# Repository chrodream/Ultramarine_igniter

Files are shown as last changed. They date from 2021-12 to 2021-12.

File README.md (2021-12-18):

# Ultramarine Igniter

## Specification

- Ergonomic key style
- OLED unit
- QMK Firmware is Ready
- RGB LED matrix (Optional)
- Li-Po Battery charge circuit included (Optional)

## Parts

- Ultramarine PCBs x 2
- Key switches x 70 (Cherry MX and Kailh low profile v1 are available)
- 1N4148W Diode x 70
- Pro micro x 70 (You can use BLE Pro micro when connect with Bluetooth)
- Reset switches x 2
- TRRS cable x 1 (Only wired connection)

### Optional parts

- SK6812 mini x 70

- OLED working with SSD1306 driver x 2 (128 x 32 pixels)

  #### Battery parts

  - Li-Po batteries x 2 
  - pCh MOSFET (Recommended AO3401)
  - MCP73831
  - DW01A
  - FS8205
  - 4.7uF Capacitor x 3
  - 0.1uF x 1
  - 0.1 Resistor x 1
  - 330

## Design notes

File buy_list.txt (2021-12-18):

main
https://akizukidenshi.com/catalog/g/gP-15370/ SLIDESW
https://akizukidenshi.com/catalog/g/gI-05866/ D
https://akizukidenshi.com/catalog/g/gI-11879/ Pow-LED
https://akizukidenshi.com/catalog/g/gI-15477/ RGB-LED
https://akizukidenshi.com/catalog/g/gC-06070/ TRRS
https://akizukidenshi.com/catalog/g/gP-08074/ TACTSW

battery area
https://www.sengoku.co.jp/mod/sgk_cart/detail.php?code=EEHD-4YZL/ Battery
https://akizukidenshi.com/catalog/g/gI-14654/ Pch MOSFET
https://akizukidenshi.com/catalog/g/gI-13288/ MCP73831 (charge unit)

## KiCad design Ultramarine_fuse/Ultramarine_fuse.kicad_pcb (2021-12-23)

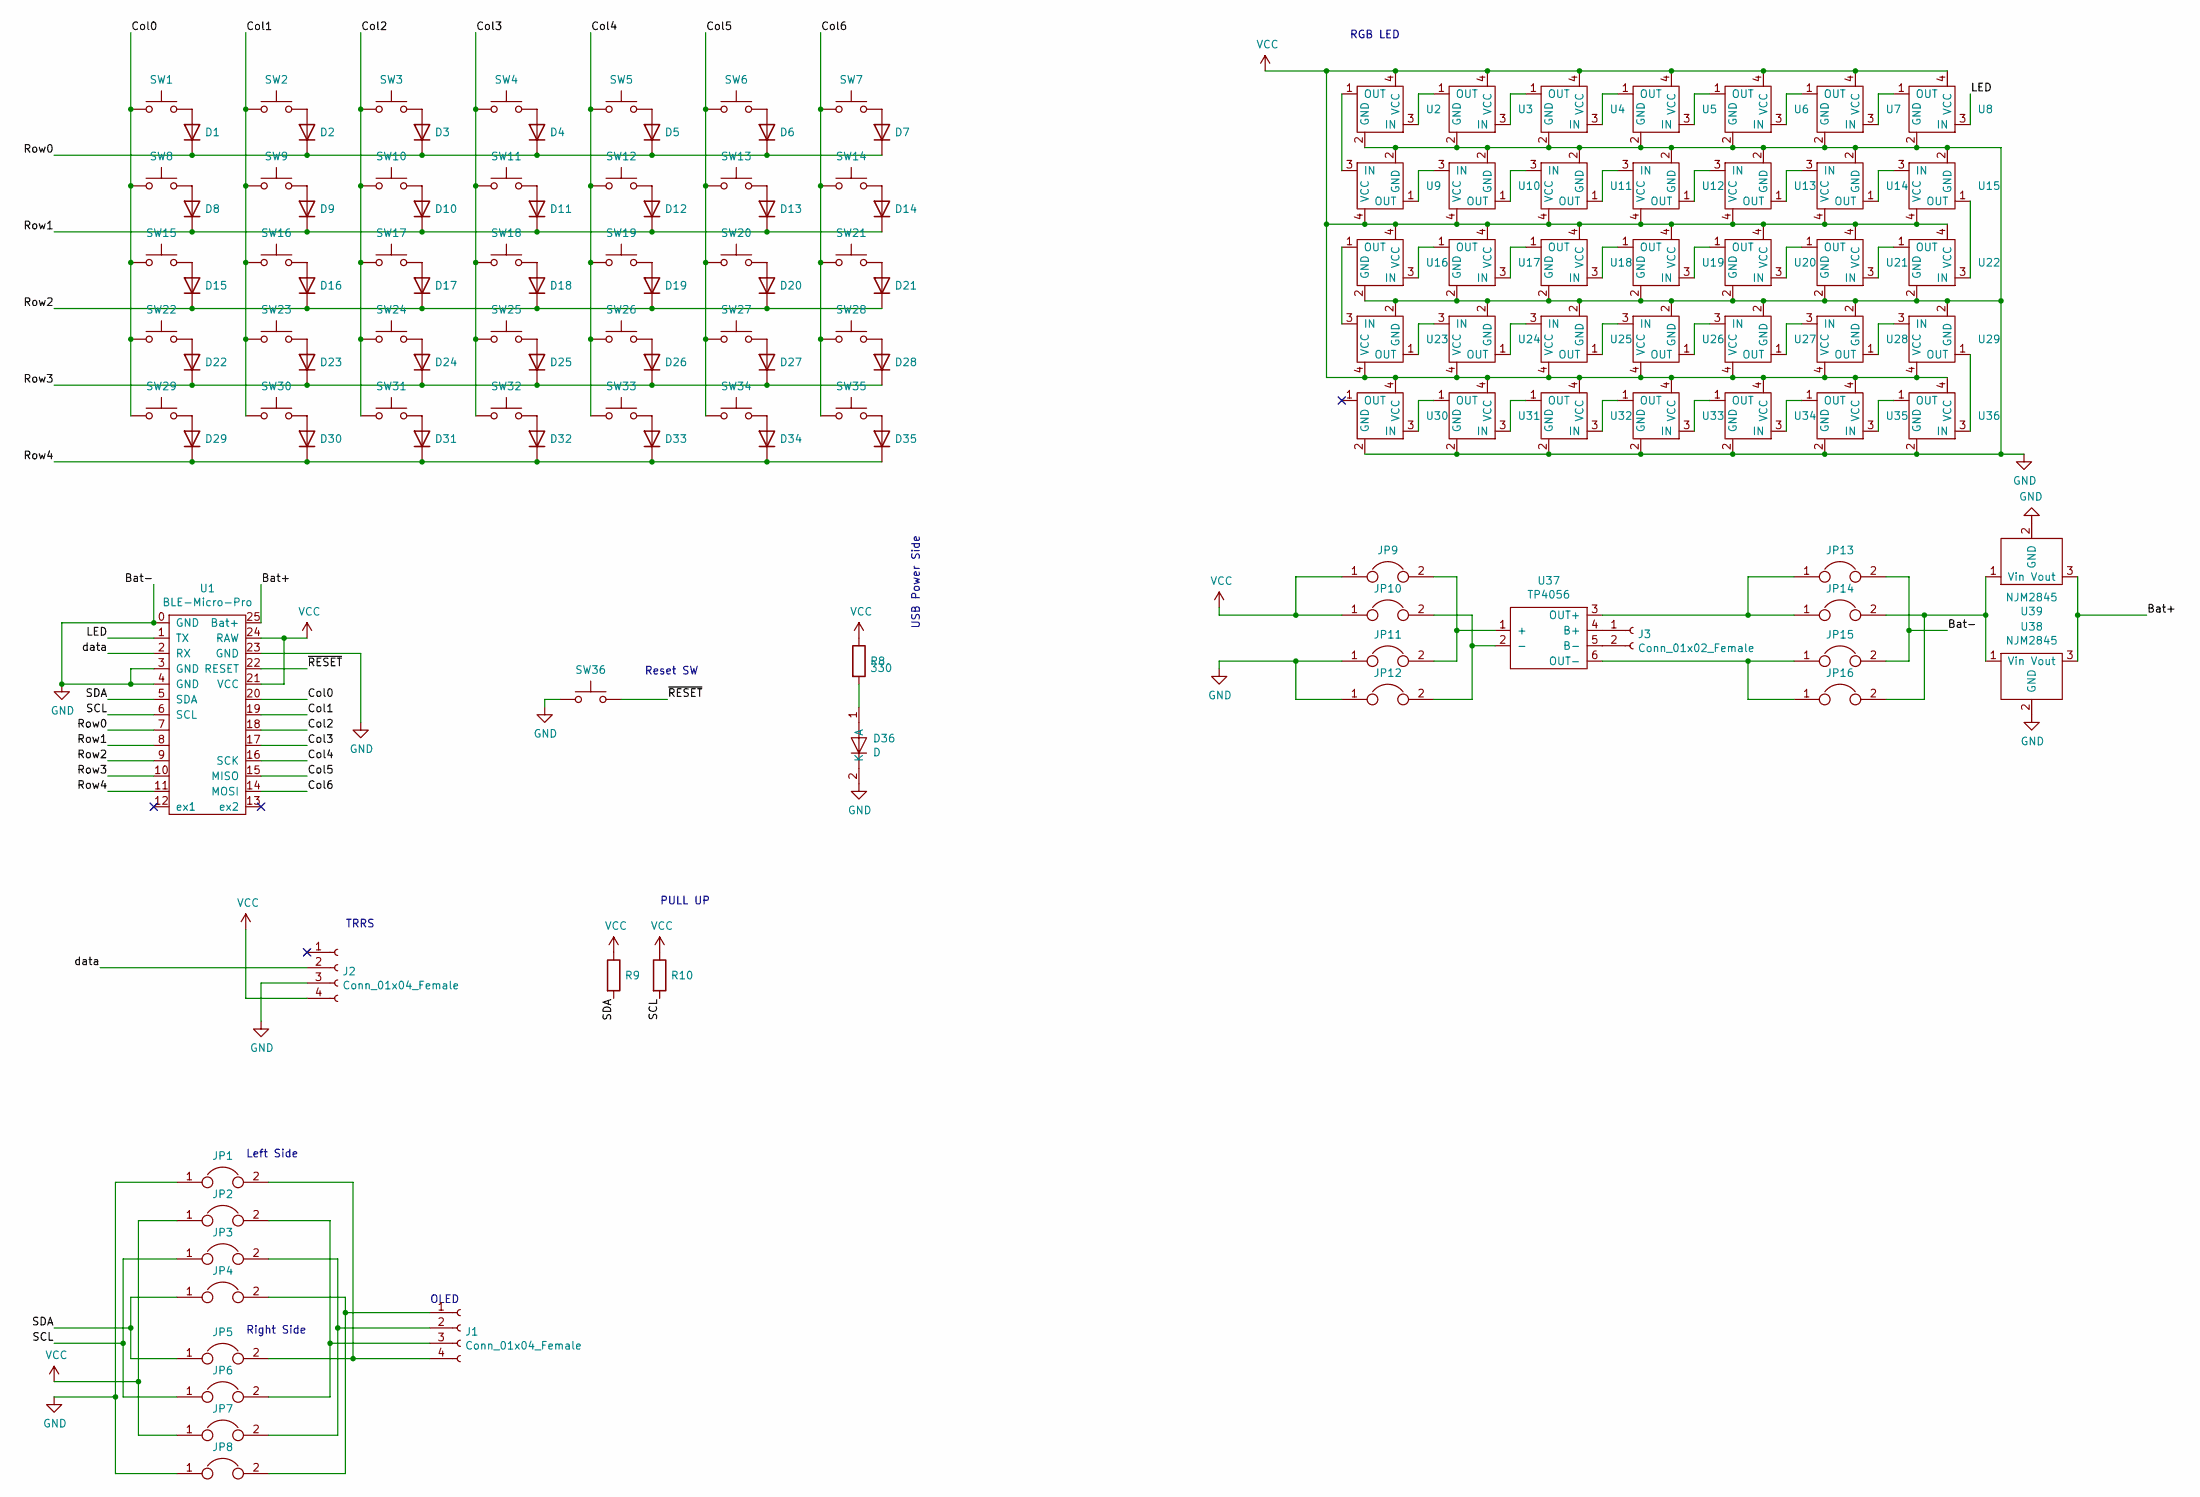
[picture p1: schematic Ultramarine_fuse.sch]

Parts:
D1, D2, D3, D4, D5, D6, D7, D8, D9, D10, D11, D12, D13, D14, D15, D16, D17, D18, D19, D20, D21, D22, D23, D24, D25, D26, D27, D28, D29, D30, D31, D32, D33, D34, D35: D; 1N4148
D36: D; LED1608
J1: Conn_01x04_Female; 4pin_A
J2: Conn_01x04_Female; TRRS
J3: Conn_01x02_Female; S2B-PH-K-S
JP1, JP2, JP3, JP4, JP5, JP6, JP7, JP8: Jumper; SMD_Jumper
JP9, JP10, JP11, JP12, JP13, JP14, JP15, JP16: Jumper; SolderJumper-2_P1.3mm_Open_RoundedPad1.0x1.5mm
R8: 330; 1608
R9, R10: 10K; 1608
SW1, SW2, SW3, SW4, SW5, SW6, SW7, SW8, SW9, SW10, SW11, SW12, SW13, SW14, SW15, SW16, SW17, SW18, SW19, SW20, SW21, SW22, SW23, SW24, SW25, SW26, SW27, SW28, SW29, SW30, SW31, SW32, SW33, SW34, SW35: SW_Push; MX-Kailh
SW36: SW_Push; TactSW
U1: BLE-Micro-Pro
U2, U3, U4, U5, U6, U7, U8, U9, U10, U11, U12, U13, U14, U15, U16, U17, U18, U19, U20, U21, U22, U23, U24, U25, U26, U27, U28, U29, U30, U31, U32, U33, U34, U35, U36: SK6812mini
U37: TP4056
U38, U39: NJM2845; TO-252-2

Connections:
/Bat+: U1.25 (Bat+), U38.3 (Vout), U39.3 (Vout)
/Col0: SW1.1, SW8.1, SW15.1, SW22.1, SW29.1, U1.20
/Col1: SW2.1, SW9.1, SW16.1, SW23.1, SW30.1, U1.19
/Col2: SW3.1, SW10.1, SW17.1, SW24.1, SW31.1, U1.18
/Col3: SW4.1, SW11.1, SW18.1, SW25.1, SW32.1, U1.17
/Col4: SW5.1, SW12.1, SW19.1, SW26.1, SW33.1, U1.16 (SCK)
/Col5: SW6.1, SW13.1, SW20.1, SW27.1, SW34.1, U1.15 (MISO)
/Col6: SW7.1, SW14.1, SW21.1, SW28.1, SW35.1, U1.14 (MOSI)
/LED: U1.1 (TX), U8.3 (IN)
/Row0: D1.1 (K), D2.1 (K), D3.1 (K), D4.1 (K), D5.1 (K), D6.1 (K), D7.1 (K), U1.7
/Row1: D8.1 (K), D9.1 (K), D10.1 (K), D11.1 (K), D12.1 (K), D13.1 (K), D14.1 (K), U1.8
/Row2: D15.1 (K), D16.1 (K), D17.1 (K), D18.1 (K), D19.1 (K), D20.1 (K), D21.1 (K), U1.9
/Row3: D22.1 (K), D23.1 (K), D24.1 (K), D25.1 (K), D26.1 (K), D27.1 (K), D28.1 (K), U1.10
/Row4: D29.1 (K), D30.1 (K), D31.1 (K), D32.1 (K), D33.1 (K), D34.1 (K), D35.1 (K), U1.11
/SCL: JP3.1, JP6.1, R10.2, U1.6 (SCL)
/SDA: JP4.1, JP5.1, R9.2, U1.5 (SDA)
/data: J2.2, U1.2 (RX)
/~RESET: SW36.2, U1.22 (RESET)
GND: D36.2 (K), J2.3, JP1.1, JP8.1, JP11.1, JP12.1, JP13.2, JP15.2, SW36.1, U1.0 (GND), U1.3 (GND), U1.4 (GND), U1.23 (GND), U2.2 (GND), U3.2 (GND), U4.2 (GND), U5.2 (GND), U6.2 (GND), U7.2 (GND), U8.2 (GND), U9.2 (GND), U10.2 (GND), U11.2 (GND), U12.2 (GND), U13.2 (GND), U14.2 (GND), U15.2 (GND), U16.2 (GND), U17.2 (GND), U18.2 (GND), U19.2 (GND), U20.2 (GND), U21.2 (GND), U22.2 (GND), U23.2 (GND), U24.2 (GND), U25.2 (GND), U26.2 (GND), U27.2 (GND), U28.2 (GND), U29.2 (GND), U30.2 (GND), U31.2 (GND), U32.2 (GND), U33.2 (GND), U34.2 (GND), U35.2 (GND), U36.2 (GND), U38.2 (GND), U39.2 (GND)
unnamed: D1.2 (A), SW1.2
unnamed: D2.2 (A), SW2.2
unnamed: D3.2 (A), SW3.2
unnamed: D4.2 (A), SW4.2
unnamed: D5.2 (A), SW5.2
unnamed: D6.2 (A), SW6.2
unnamed: D7.2 (A), SW7.2
unnamed: D8.2 (A), SW8.2
unnamed: D9.2 (A), SW9.2
unnamed: D10.2 (A), SW10.2
unnamed: D11.2 (A), SW11.2
unnamed: D12.2 (A), SW12.2
unnamed: D13.2 (A), SW13.2
unnamed: D14.2 (A), SW14.2
unnamed: D15.2 (A), SW15.2
unnamed: D16.2 (A), SW16.2
unnamed: D17.2 (A), SW17.2
unnamed: D18.2 (A), SW18.2
unnamed: D19.2 (A), SW19.2
unnamed: D20.2 (A), SW20.2
unnamed: D21.2 (A), SW21.2
unnamed: D22.2 (A), SW22.2
unnamed: D23.2 (A), SW23.2
unnamed: D24.2 (A), SW24.2
unnamed: D25.2 (A), SW25.2
unnamed: D26.2 (A), SW26.2
unnamed: D27.2 (A), SW27.2
unnamed: D28.2 (A), SW28.2
unnamed: D29.2 (A), SW29.2
unnamed: D30.2 (A), SW30.2
unnamed: D31.2 (A), SW31.2
unnamed: D32.2 (A), SW32.2
unnamed: D33.2 (A), SW33.2
unnamed: D34.2 (A), SW34.2
unnamed: D35.2 (A), SW35.2
unnamed: D36.1 (A), R8.2
unnamed: J1.1, JP4.2, JP8.2
unnamed: J1.2, JP3.2, JP7.2
unnamed: J1.3, JP2.2, JP6.2
unnamed: J1.4, JP1.2, JP5.2
unnamed: J3.1, U37.4 (B+)
unnamed: J3.2, U37.5 (B-)
unnamed: JP10.2, JP12.2, U37.2 (-)
unnamed: JP9.2, JP11.2, U37.1 (+)
unnamed: JP13.1, JP14.1, U37.3 (OUT+)
unnamed: JP14.2, JP16.2, U38.1 (Vin), U39.1 (Vin)
unnamed: JP15.1, JP16.1, U37.6 (OUT-)
unnamed: U2.1 (OUT), U9.3 (IN)
unnamed: U2.3 (IN), U3.1 (OUT)
unnamed: U3.3 (IN), U4.1 (OUT)
unnamed: U4.3 (IN), U5.1 (OUT)
unnamed: U5.3 (IN), U6.1 (OUT)
unnamed: U6.3 (IN), U7.1 (OUT)
unnamed: U7.3 (IN), U8.1 (OUT)
unnamed: U10.1 (OUT), U11.3 (IN)
unnamed: U9.1 (OUT), U10.3 (IN)
unnamed: U11.1 (OUT), U12.3 (IN)
unnamed: U12.1 (OUT), U13.3 (IN)
unnamed: U13.1 (OUT), U14.3 (IN)
unnamed: U14.1 (OUT), U15.3 (IN)
unnamed: U15.1 (OUT), U22.3 (IN)
unnamed: U16.1 (OUT), U23.3 (IN)
unnamed: U16.3 (IN), U17.1 (OUT)
unnamed: U17.3 (IN), U18.1 (OUT)
unnamed: U18.3 (IN), U19.1 (OUT)
unnamed: U19.3 (IN), U20.1 (OUT)
unnamed: U20.3 (IN), U21.1 (OUT)
unnamed: U21.3 (IN), U22.1 (OUT)
unnamed: U23.1 (OUT), U24.3 (IN)
unnamed: U24.1 (OUT), U25.3 (IN)
unnamed: U25.1 (OUT), U26.3 (IN)
unnamed: U26.1 (OUT), U27.3 (IN)
unnamed: U27.1 (OUT), U28.3 (IN)
unnamed: U28.1 (OUT), U29.3 (IN)
unnamed: U29.1 (OUT), U36.3 (IN)
unnamed: U30.3 (IN), U31.1 (OUT)
unnamed: U31.3 (IN), U32.1 (OUT)
unnamed: U32.3 (IN), U33.1 (OUT)
unnamed: U33.3 (IN), U34.1 (OUT)
unnamed: U34.3 (IN), U35.1 (OUT)
unnamed: U35.3 (IN), U36.1 (OUT)
VCC: J2.4, JP2.1, JP7.1, JP9.1, JP10.1, R8.1, R9.1, R10.1, U1.21 (VCC), U1.24 (RAW), U2.4 (VCC), U3.4 (VCC), U4.4 (VCC), U5.4 (VCC), U6.4 (VCC), U7.4 (VCC), U8.4 (VCC), U9.4 (VCC), U10.4 (VCC), U11.4 (VCC), U12.4 (VCC), U13.4 (VCC), U14.4 (VCC), U15.4 (VCC), U16.4 (VCC), U17.4 (VCC), U18.4 (VCC), U19.4 (VCC), U20.4 (VCC), U21.4 (VCC), U22.4 (VCC), U23.4 (VCC), U24.4 (VCC), U25.4 (VCC), U26.4 (VCC), U27.4 (VCC), U28.4 (VCC), U29.4 (VCC), U30.4 (VCC), U31.4 (VCC), U32.4 (VCC), U33.4 (VCC), U34.4 (VCC), U35.4 (VCC), U36.4 (VCC)

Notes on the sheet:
Right Side
Left Side
Reset SW
TRRS
OLED
RGB LED
PULL UP
USB Power Side

Board: 2 copper layers, 133 parts (10 on the bottom side), 101 nets, no tracks yet.

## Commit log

2021-08-27 nothing special
    [Ultramarine_fuse.kicad_pcb, Ultramarine_fuse.sch]
2021-09-19 PCB making without Charging unit is completed
    [Ultramarine_fuse.kicad_pcb, Ultramarine_fuse.sch]
2021-12-18 fixed charge circuit for TP4056
    [Ultramarine_fuse.dsn, Ultramarine_fuse.kicad_pcb, Ultramarine_fuse.sch]
2021-12-23 add 3v3 regulator
    [Ultramarine_fuse.dsn, Ultramarine_fuse.kicad_pcb, Ultramarine_fuse.sch]
